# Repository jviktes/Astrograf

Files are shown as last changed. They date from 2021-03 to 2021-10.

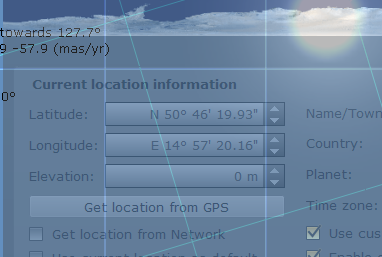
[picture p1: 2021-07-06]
AstroCalc/Images/2021-07-05 17_04_42-Stellarium 0.21.0.png

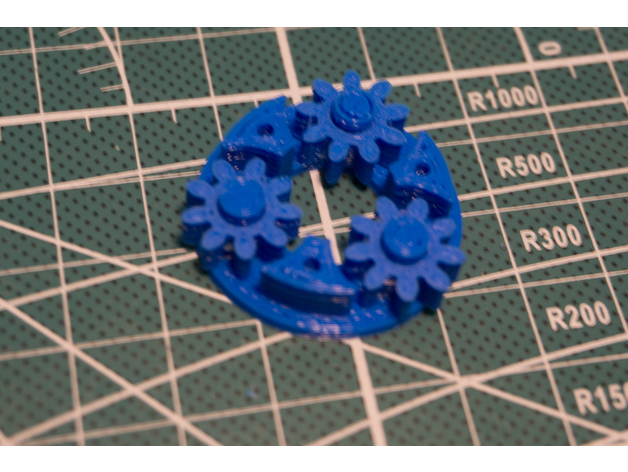
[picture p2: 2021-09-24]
3DPrint/Modular_planetary_gearbox__1024/images/89b79a1b9589dc2109ac6e01d3e06d19_preview_featured.jpg

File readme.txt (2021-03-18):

Projekt má několik částí:
1/ Teorie pro azimutánní montáž vs paraliktická - pro začátek je jednodušší azimutání, dále pak mohu využít pro sledování letadel, AM je výhodná pro zemské sledování
Z Planetiriá si najdu objekt a jeho souřadnice, ty pak pošlu an dalekohled a ten se natočí a začne stremovat/fotit 

2/ Pohony - asi zvolím krokový motorek. 
Problémy: při přetížení ztráta kroku - jak to sledovat s nějakou šablonou, možná by pomohly čidla z optické myši a pokud to nějak neodpovídá, pak kalibrovat. Počítat všechny kroky motoru + - a ukazovat pořád aktuální úhel...

3/ Konstrukce:
šnek a převody a další převody do nějakého poměru ,aby asi 50.000 otáček motoru byla jedna otáčka dalekohledu, zvýší se tím asi i přesnost

4/ Ovládání:
elegatní přes aplikaci v mobilu nebo PC program

5/ Focení letadel - je to vůbec možné, zkusit na jedné ose, čeká se na spojení s USB dongle odposlechem

Odkazy:
Převodovky a ozubená kola:
https://www.mateza.cz/e-shop/prevodovky/ozubena-kola/ozubena-kola-celni

https://www.astro.cz/clanky/ostatni/teleskopie-dil-ctrnacty-jednoduche-zarizeni-pro-astrografii.html

https://www.ngc7000.com/telescope-motorization.htm

https://www.instructables.com/Star-Track-Arduino-Powered-Star-Pointer-and-Tracke/

Astro tracker

Hotový hodinová strojek:
https://nl.aliexpress.com/item/4000115759057.html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,scm-url:1007.13339.169870.0,pvid:6c359c70-a61f-4515-a4be-b17c4211bed0,tpp_buckets:668%230%23131923%230_668%230%23131923%230_668%23888%233325%2320_668%23888%233325%2320_668%232846%238108%231977_668%232717%237560%23237_668%231000022185%231000066059%230_668%233468%2315617%23817_668%232846%238108%231977_668%232717%237560%23237_668%233164%239976%23517_668%233468%2315617%23817

Cíl:
https://www.moveshootmove.com

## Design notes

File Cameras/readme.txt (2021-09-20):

Kamery přímo do dalekohledu:

https://www.aliexpress.com/item/10000111526603.html

Co mám doma:
computar tv zoom lens t6y5710Amsp - zaostřování, clona atd. pomocí motorků, nástavba k EYE03

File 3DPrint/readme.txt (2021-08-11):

Worm gearbox 1:60
https://www.thingiverse.com/thing:3079719

Compound Planetary Gearbox For Robotic Arm Project 43.3:1 
https://www.thingiverse.com/thing:2101218/comments

Hujer - modulární planetová převodovka
https://www.thingiverse.com/thing:2586962

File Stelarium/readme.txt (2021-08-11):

Původní projekt:

https://www.instructables.com/Control-Your-Telescope-Using-Stellarium-Arduino/
!!! pozor tento projekt není zcela funkční !!!

Data zachycená na mySerial = to co se posílá do Stelaria:

AR03:33:55#txDEC+86?08:57
AR03:35:04#txDEC+86?08:57
AR03:36:55#txDEC+86?08:57#

Spouštět jako admin!
Správný protokol.

Alternativy
http://www.skytechx.eu/?page=home

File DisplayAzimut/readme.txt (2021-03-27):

V některých knihovnách je problém, že neukazují přímo úhly, ale nějaké přírústky v čase nebo co.

tato knihovna (AHRS) ukazuje rovnou úhly:
AHRS is an acronym for Attitude and Heading Reference System, a system generally used for aircraft of any sort to determine heading, pitch, roll, altitude etc.

https://learn.adafruit.com/ahrs-for-adafruits-9-dof-10-dof-breakout?v

Pro LCD display toto:
https://lastminuteengineers.com/i2c-lcd-arduino-tutorial/

Pokusy s měřením pomocí gyroskoupu:

úhly mají v bytě podivné odchylky

magnetická odchylka pro dané místo
https://www.ngdc.noaa.gov/geomag/calculators/magcalc.shtml?#declination

Zde se počítá azimut - mezi 2 body
https://www.calcmaps.com/map-coordinates/ -> https://www.omnicalculator.com/other/azimuth
Naměřené úhly:
50.76197,15.09745 domov
50.73269,14.98462 Jested

LBC --> komín Rýnovice: 125.88 vzdálenost: 4.4km
LBC -->Ještěd: 247.74, vzdálenost: 8.58km

Odchylka na Ješted je asi 10st, na komín asi 20, stejně tak na Měsíc. Snaha o kalibraci aplikace Kompas v mobilu, ale také ukazuje podivnosti, na Ještě d celkem ok +-2 st, možná i přesněji, na komín ale stále +-10, nerozumím. Je nutná důsledná kalibrace sensoru např. podle https://learn.adafruit.com/adafruit-sensorlab-magnetometer-calibration?view=all
--> opouštím od magnetických sensorů, jsou velice nepřesné a pokusím se udělat to přes motorky a počítání kroků a kalibraci se zaměřením na Ještěd a odpočtu známého azimutu.

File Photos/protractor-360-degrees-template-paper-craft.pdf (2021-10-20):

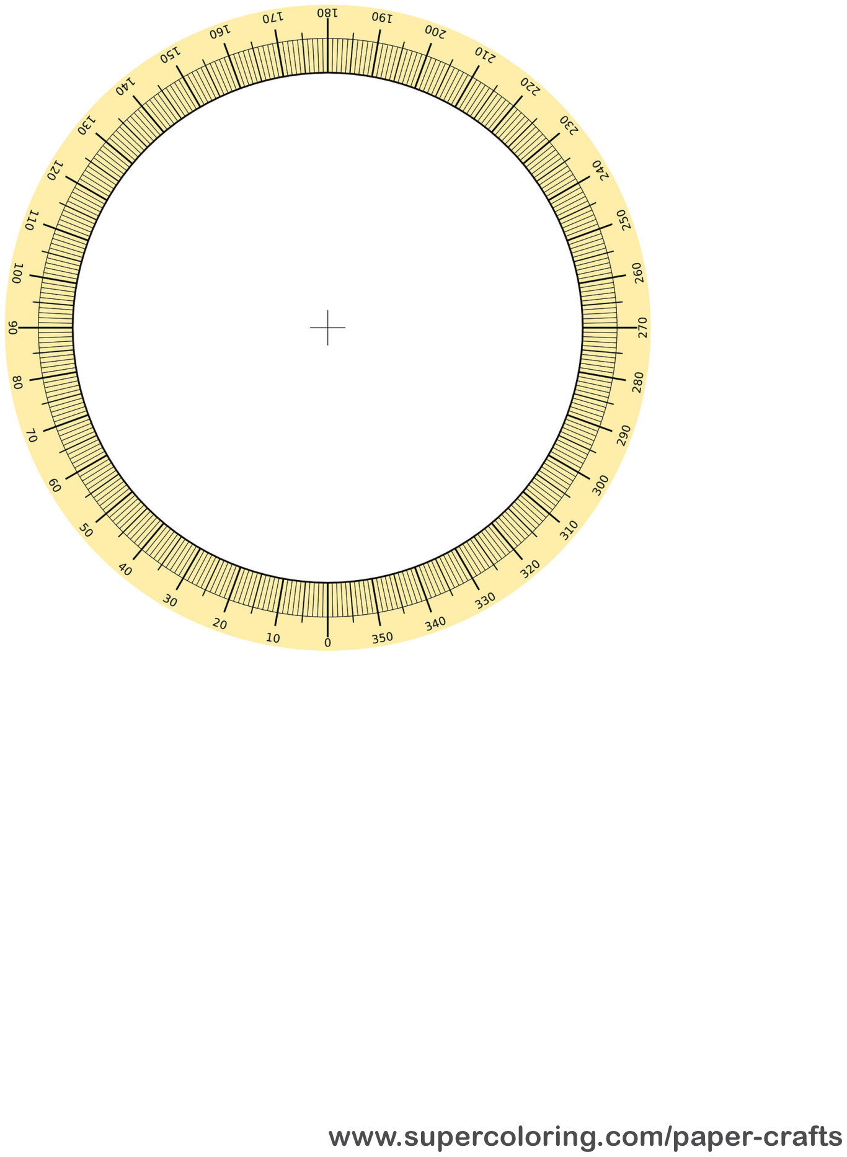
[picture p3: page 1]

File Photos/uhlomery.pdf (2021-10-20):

# Sada úhlomìrù

# Václav Piskaè, Brno 2010

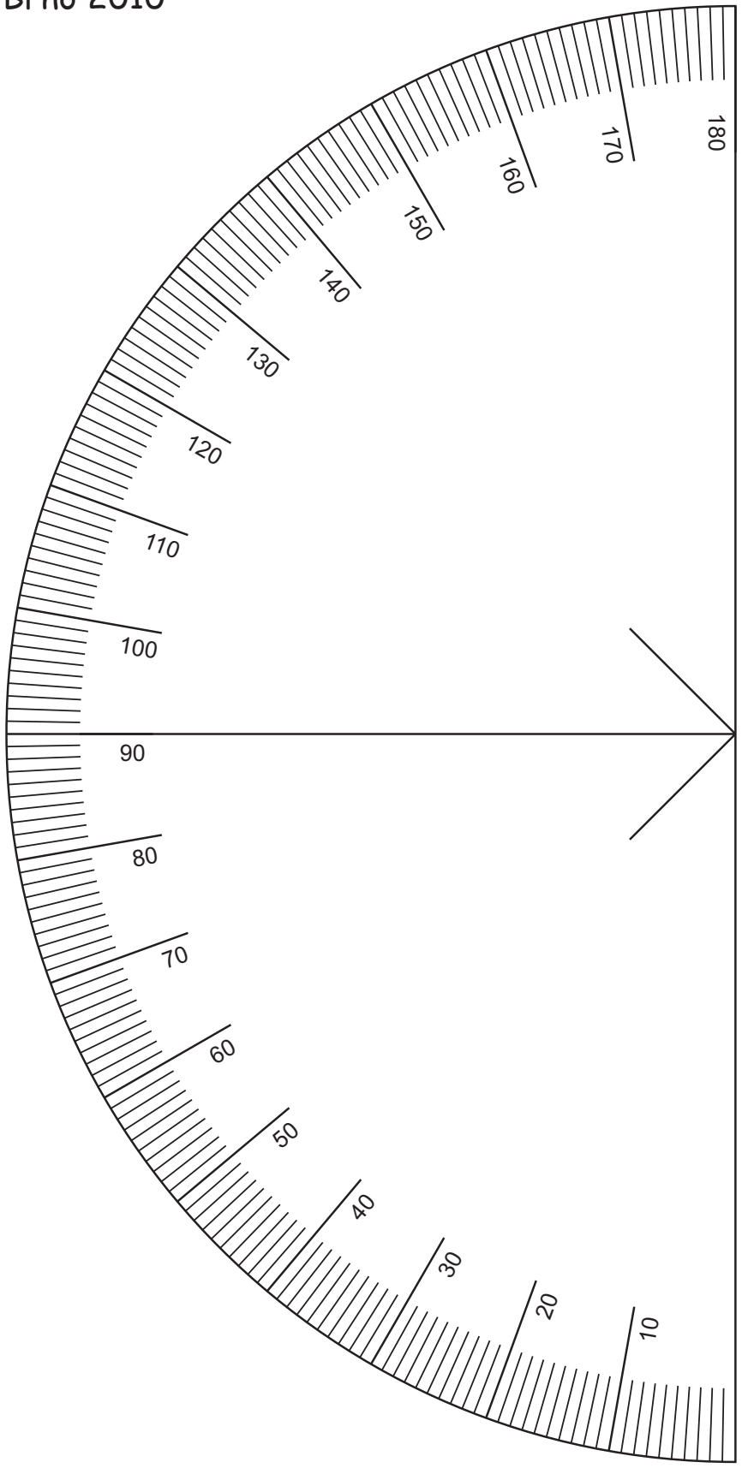
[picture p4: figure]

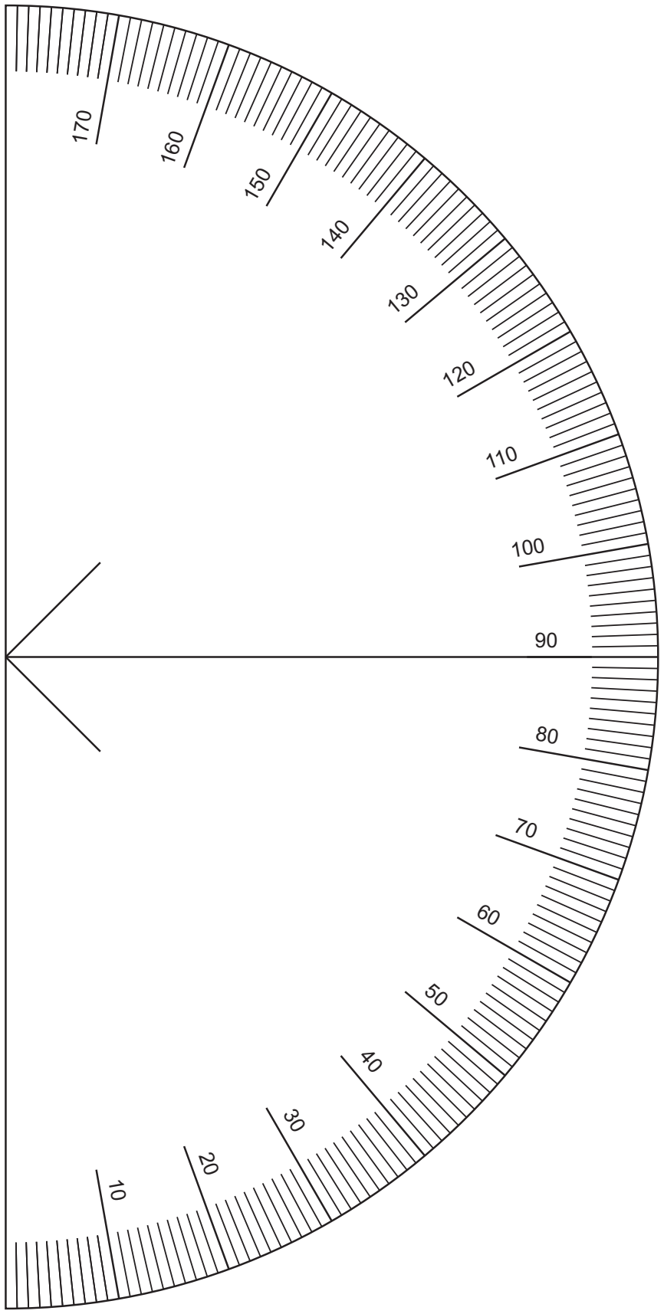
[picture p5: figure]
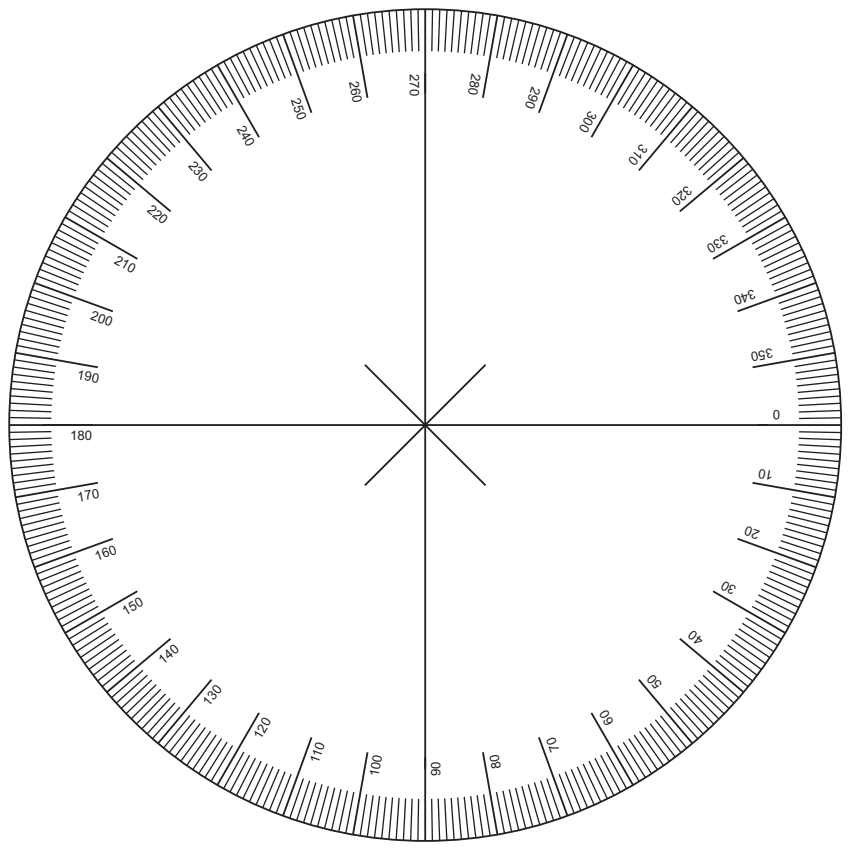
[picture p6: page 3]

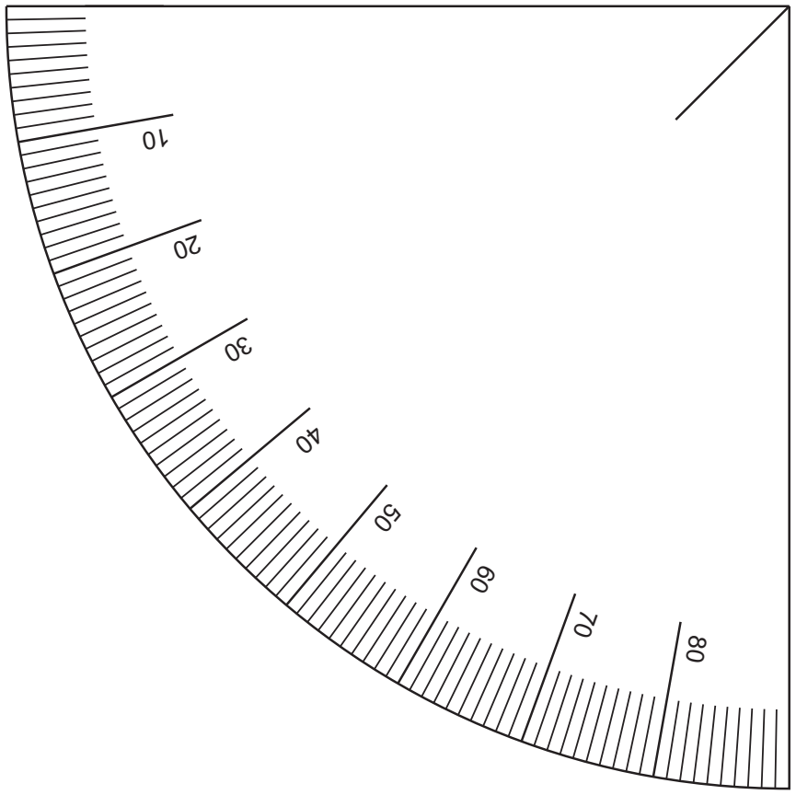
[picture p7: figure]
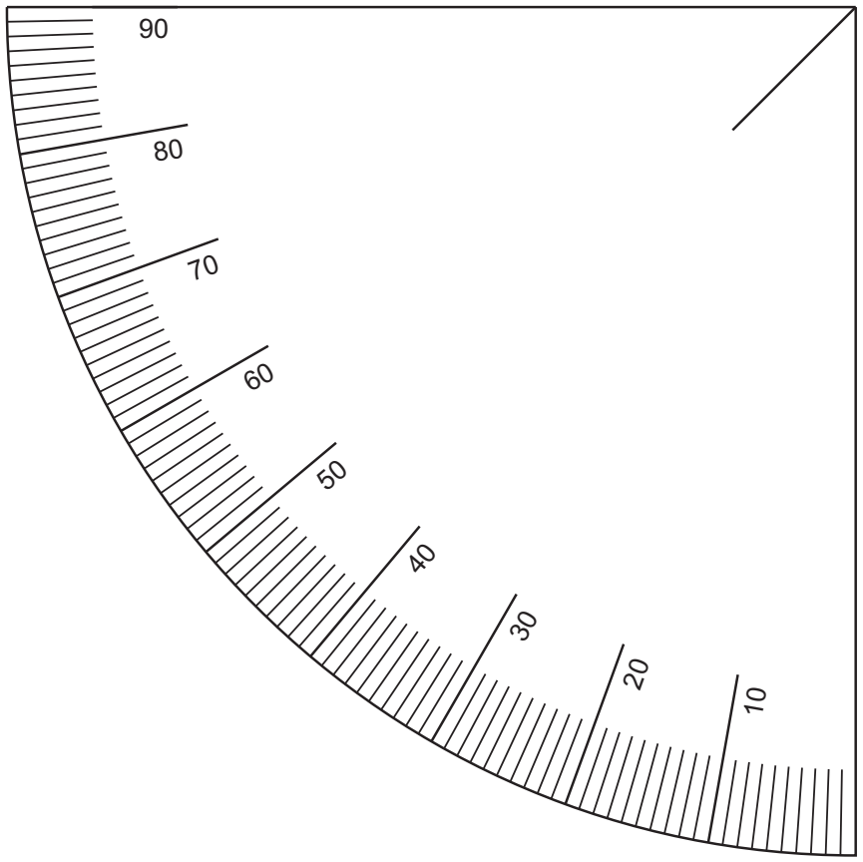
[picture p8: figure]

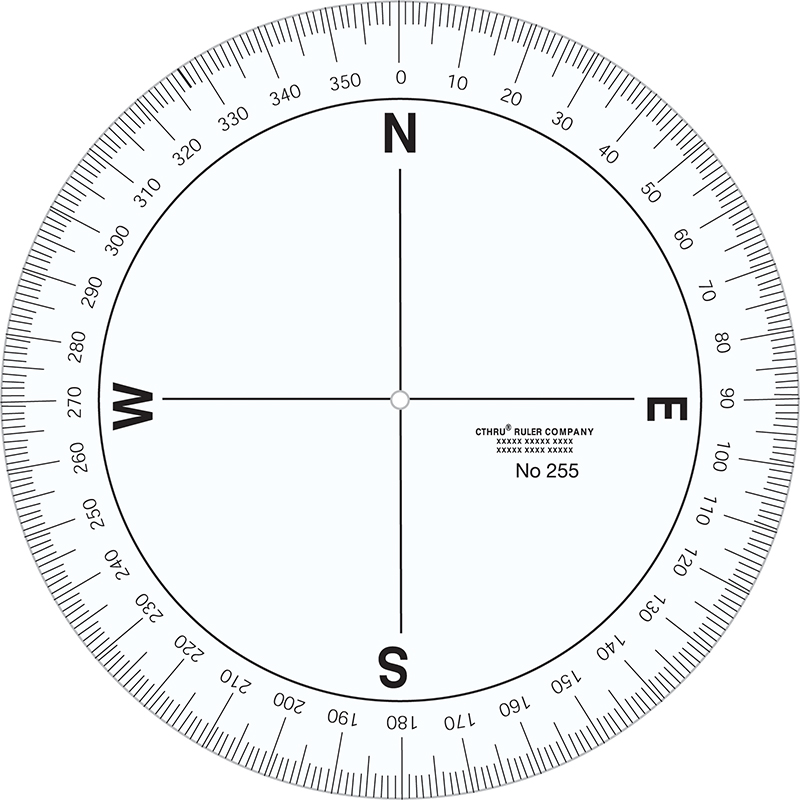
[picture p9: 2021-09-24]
Photos/azimut.jpg

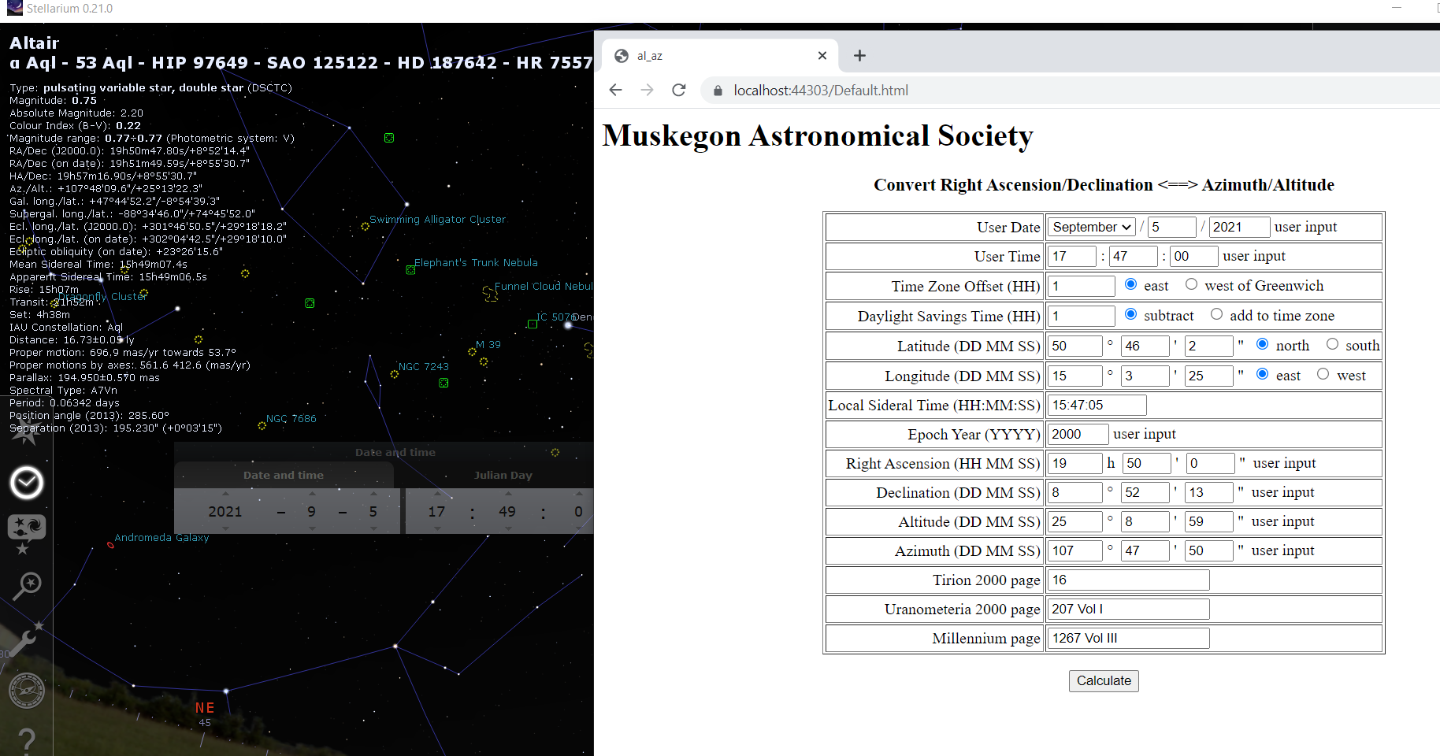
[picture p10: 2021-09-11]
Photos/2021-09-05 17_49_00-al_az.png

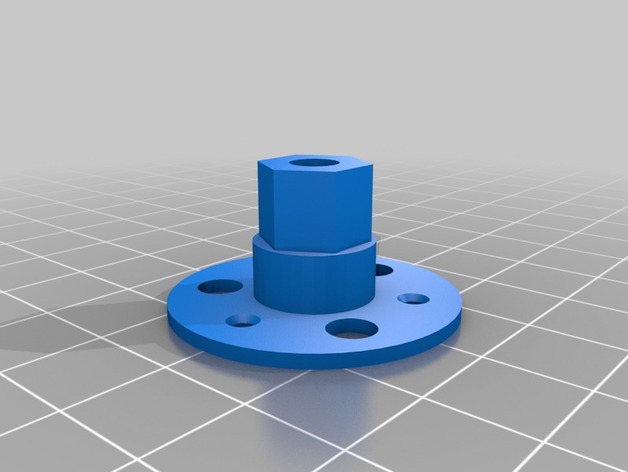
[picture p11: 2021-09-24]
3DPrint/Modular_planetary_gearbox__1024/images/2216a9d065c5c32abdc0daf6dab2dc04_preview_featured.jpg

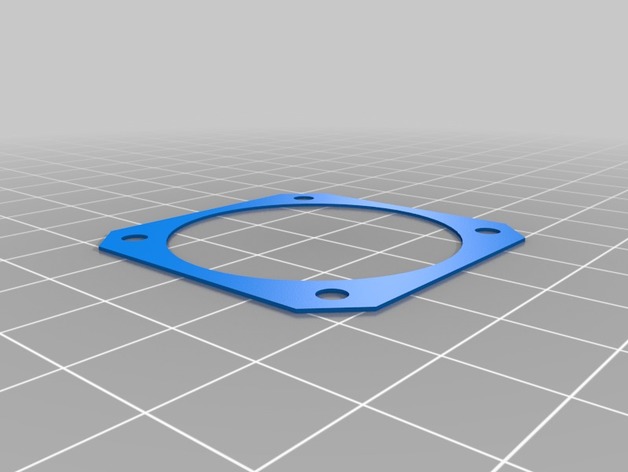
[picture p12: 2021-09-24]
3DPrint/Modular_planetary_gearbox__1024/images/d6676b2a3f6b6646a97d470c4b08ee19_preview_featured.jpg

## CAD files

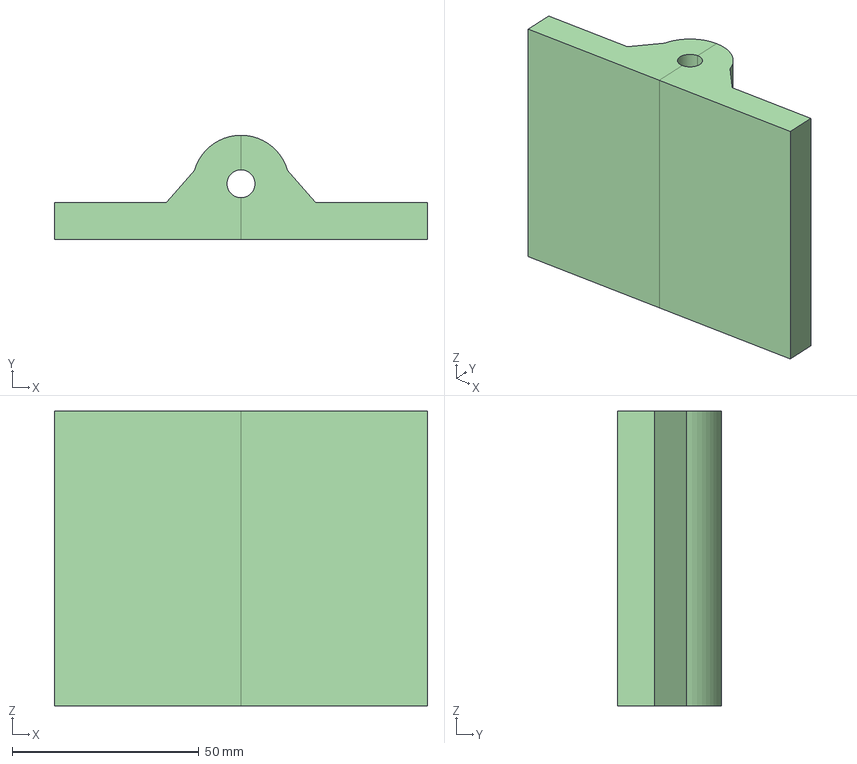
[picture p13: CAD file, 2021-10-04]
3DPrint/Models/Zrcadlovka_1.FCStd
100.0 x 28.0 x 79.0 mm
refer_vzpera
BaseFeature001

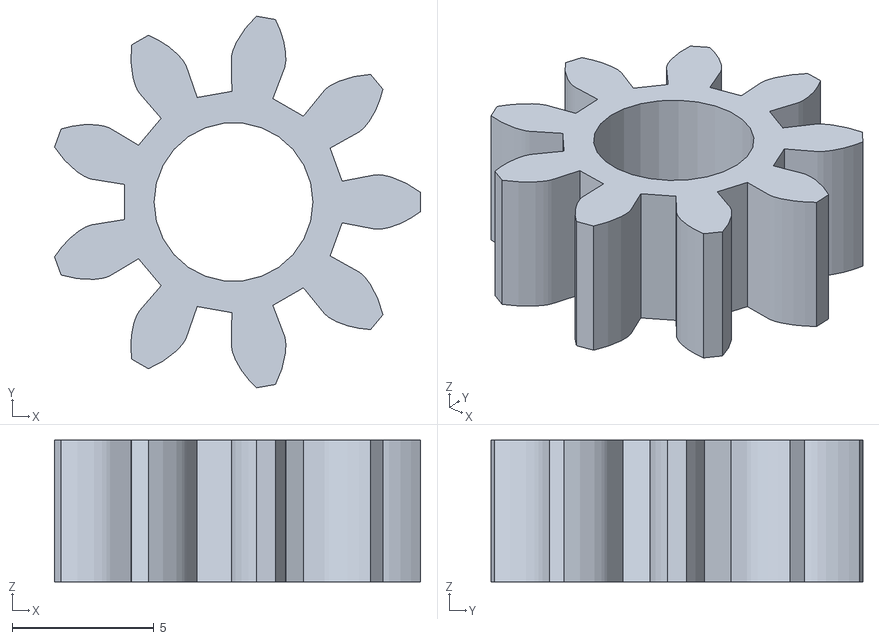
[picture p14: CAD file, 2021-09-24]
3DPrint/Modular_planetary_gearbox__1024/files/planet_gear_v1.stl
12.9 x 13.1 x 5.00

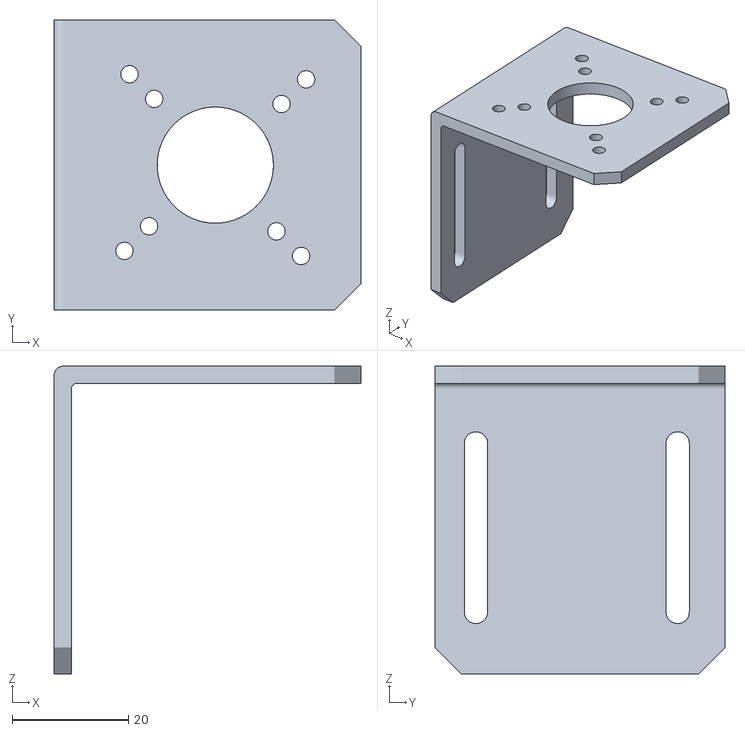
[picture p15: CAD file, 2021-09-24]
3DPrint/Nema_17_holder/files/Mounting_Bracket_for_Geared_Nema_17_-_ST-M1.stl
52.8 x 50.0 x 53.0

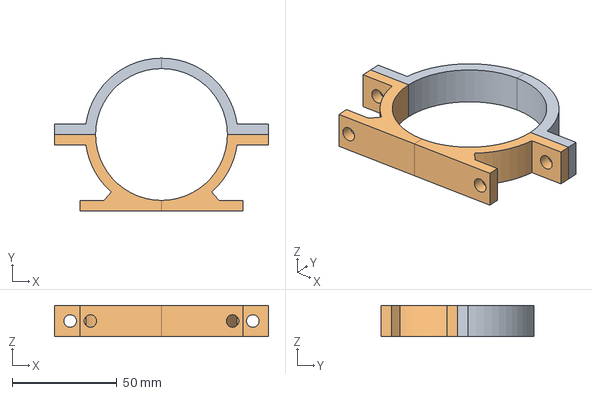
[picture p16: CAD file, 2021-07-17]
3DPrint/Telescope3D/Sverka.FCStd
102.3 x 73.0 x 15.0 mm
HorniDil
SpodniDil

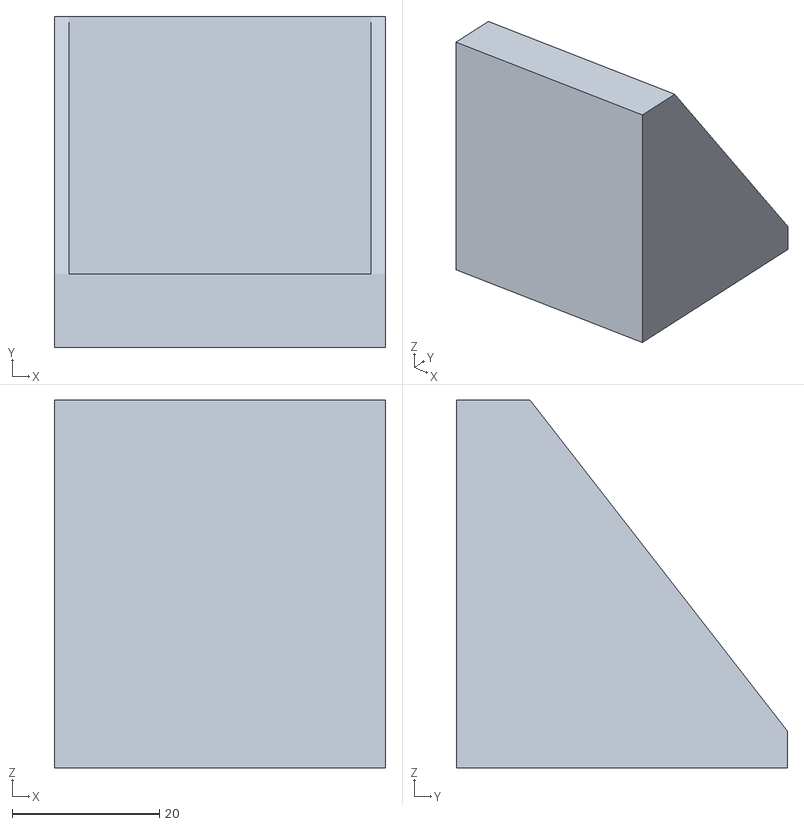
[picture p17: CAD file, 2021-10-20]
DSLR/3D_models/_backUp/Drzak_Y28_motoru_2.stl
45.0 x 45.0 x 50.0

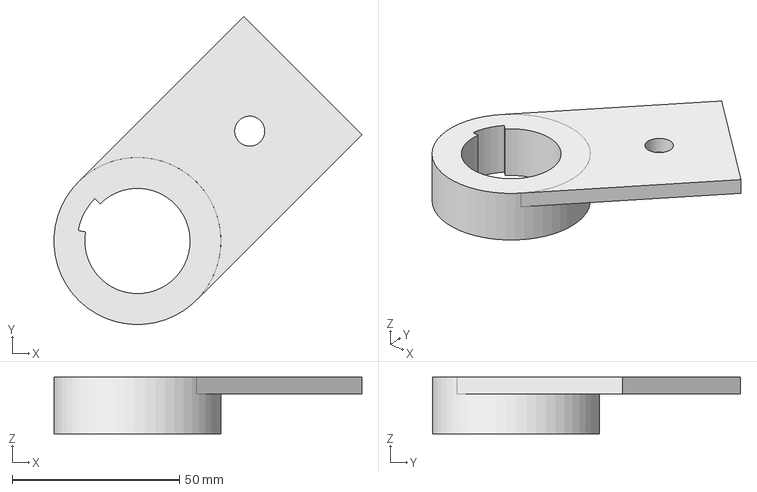
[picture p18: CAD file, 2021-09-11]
3DPrint/Models/azimut_mount.FCStd
92.1 x 92.2 x 17.0 mm

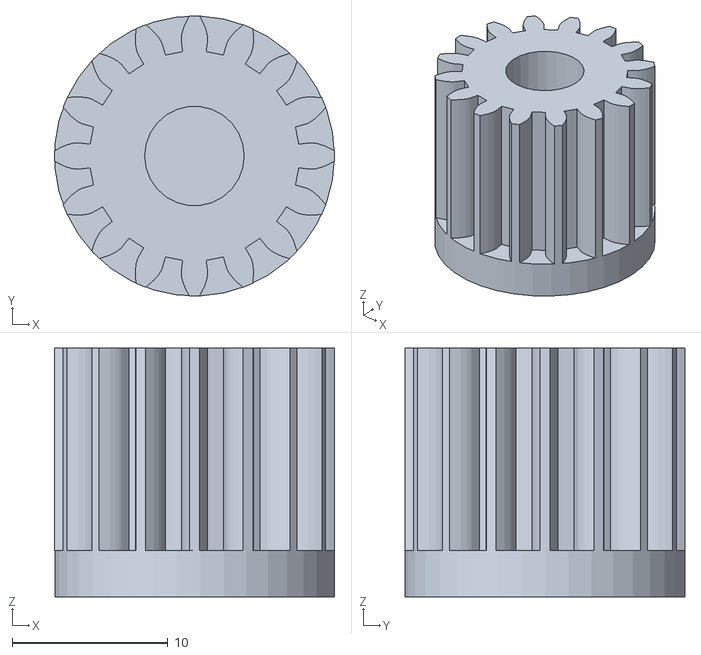
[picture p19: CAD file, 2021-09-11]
3DPrint/Models/tisk/ozub_kolo_poten_16.stl
18.0 x 18.0 x 16.0

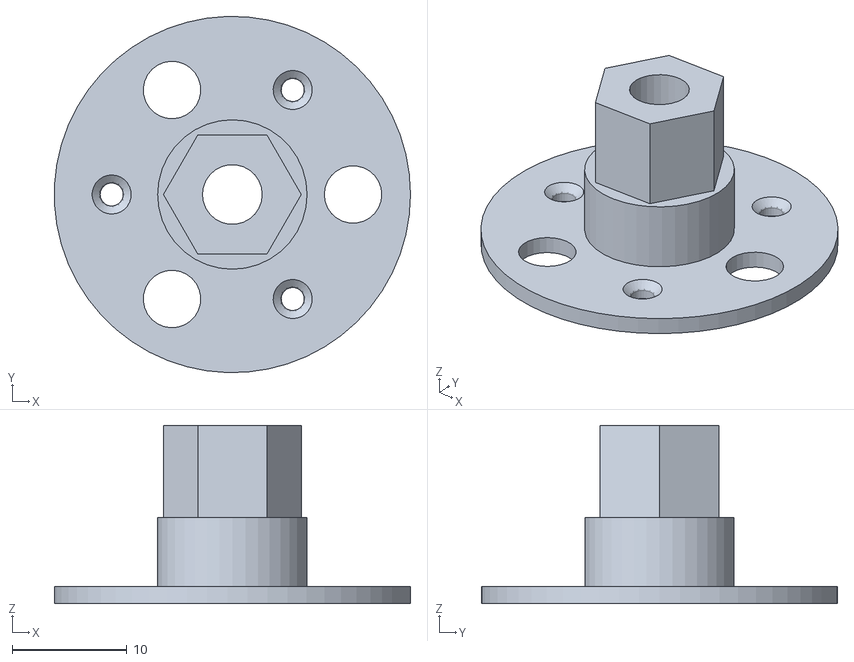
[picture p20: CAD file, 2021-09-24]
3DPrint/Modular_planetary_gearbox__1024/files/top_gear_v1.stl
31.0 x 31.0 x 15.5

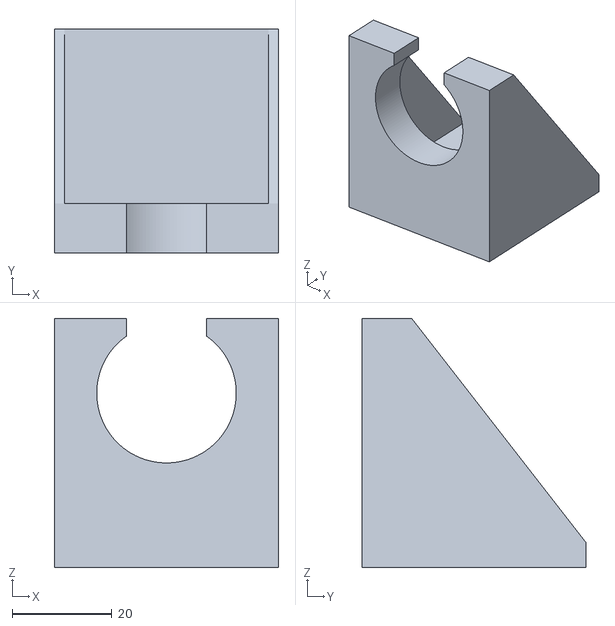
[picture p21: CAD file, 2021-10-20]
DSLR/3D_models/_backUp/Drzak_Y28_motoru_3-Fusion.stl
45.0 x 45.0 x 50.0

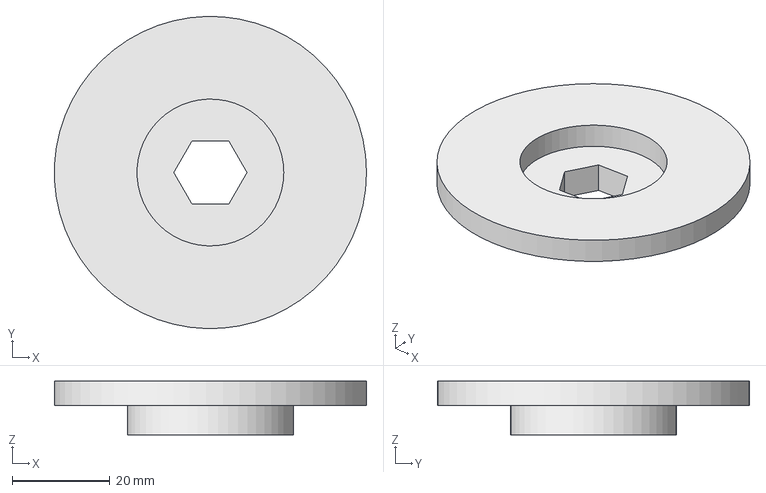
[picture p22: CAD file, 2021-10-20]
DSLR/3D_models/Zrcadlovka_Ozubena_kola_2_zavitova_hridel_priruba.FCStd
64.0 x 64.0 x 11.0 mm

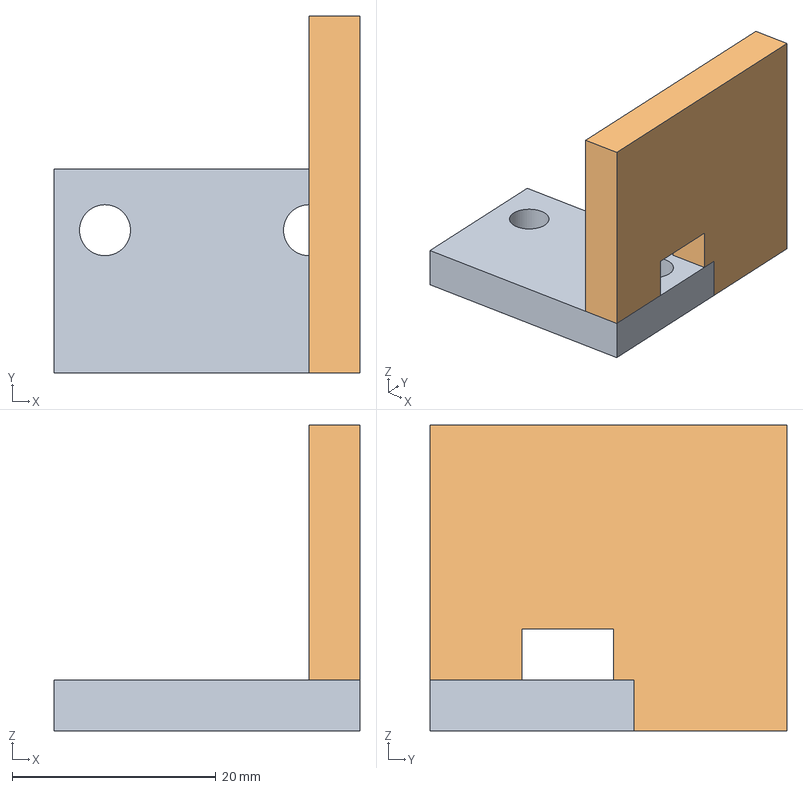
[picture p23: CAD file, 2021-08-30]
3DPrint/Models/drzak_deklinacni_potenciometr.FCStd
30.0 x 35.0 x 30.0 mm

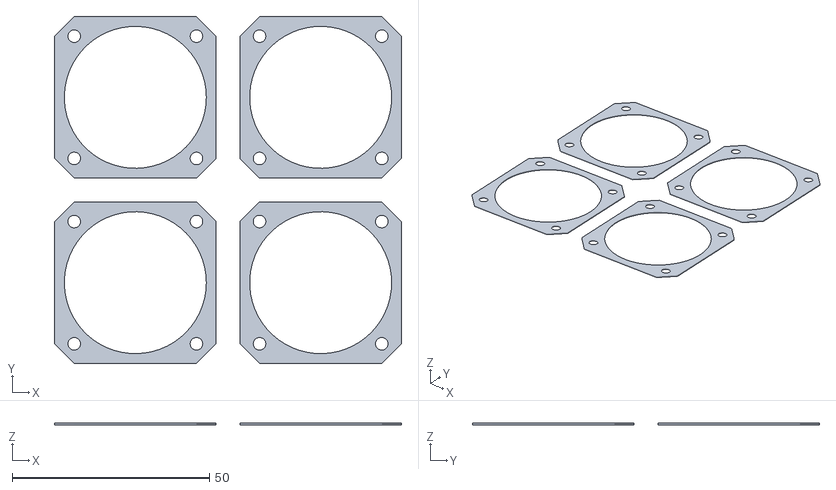
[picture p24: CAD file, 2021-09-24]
3DPrint/Modular_planetary_gearbox__1024/files/print_part_III_v1.stl
88.0 x 88.0 x 0.45

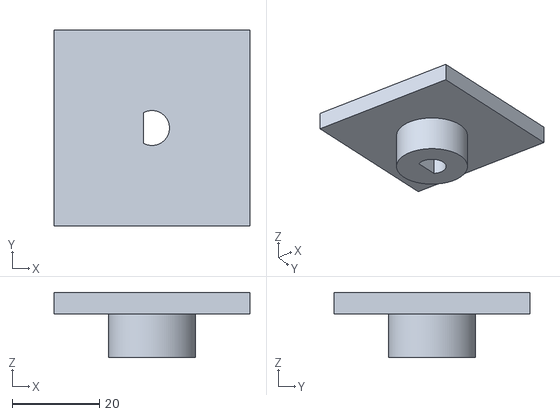
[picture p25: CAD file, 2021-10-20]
DSLR/3D_models/_backUp/hlinik_profil_v_2.stl
45.0 x 45.0 x 15.0

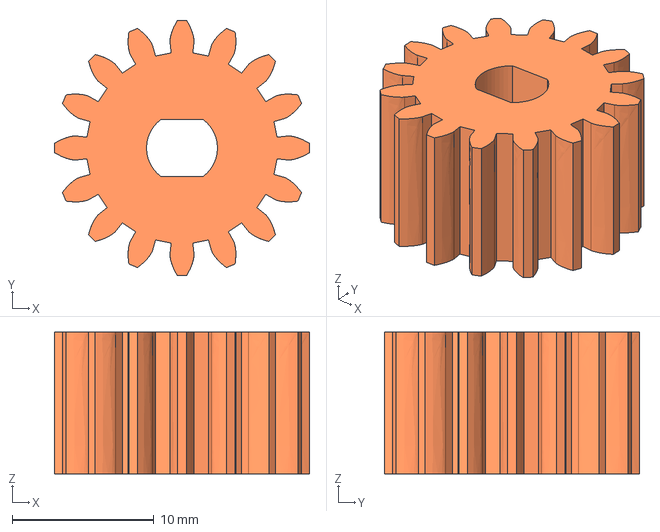
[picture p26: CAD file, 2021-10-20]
DSLR/3D_models/Zrcadlovka_Ozubena_kola_2_uprava_pro_28BYJ.FCStd
18.0 x 18.0 x 10.0 mm

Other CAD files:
DSLR/3D_models/Drzak_Y28_motoru_2.FCStd
3DPrint/Models/tisk/azimut_mount_v5.stl
3DPrint/Models/drzak_deklinacni_potenciometr-Body.stl
3DPrint/Modular_planetary_gearbox__1024/files/carrier_I_v1.stl
3DPrint/Models/azimut_mount_v1.FCStd
3DPrint/Models/azimut_mount_v2.FCStd
3DPrint/Models/new_vzpera1.FCStd
3DPrint/Models/tisk/azimut_mount-AzimutDil.stl
3DPrint/Models/tisk/azimut_mount-Male_ozub_kolo.stl
3DPrint/Models/tisk/azimut_mount-Potenciometer_kolecko.stl
3DPrint/Models/tisk/azimut_mount-Potenciometer_kolecko_v2.stl
3DPrint/Models/tisk/azimut_mount_v3.stl
3DPrint/Models/tisk/azimut_mount_v4.stl
3DPrint/Models/tisk/drzak.stl
3DPrint/Models/tisk/new_vzpera2.stl
3DPrint/Models/tisk/objimka.stl
3DPrint/Models/tisk/objimka_2.stl
3DPrint/Models/tisk/ozub_kolo_potenciometre.stl
3DPrint/Models/tisk/polovicni_ozubi.stl
3DPrint/Modular_planetary_gearbox__1024/files/body_II_v1.stl
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

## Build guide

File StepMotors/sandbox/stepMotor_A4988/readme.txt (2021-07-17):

toto je prvni výkop a hrání si s motorkem

Kontroler - návody:

https://navody.dratek.cz/navody-k-produktum/arduino-cnc-shield-driver-a4988-motor-28byj-48.html
https://dratek.cz/arduino/1133-motor-driver-a4988-pro-reprap-3d-tiskarny.html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

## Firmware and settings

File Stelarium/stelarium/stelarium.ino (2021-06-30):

#include <SoftwareSerial.h>

//**********************************************
// Config your sensor pins and location here!
//**********************************************

// Define the number of pulses that your encoder (1 and 2) gives by turn, and multiply by 4
// In my case: 600 x 15 x 4  (600 pulses by turn; 15 is the gear ratio), so:
long TOTAL_PULSES_PER_ROUND_ENC_1 = 36000;              
long TOTAL_PULSES_PER_ROUND_ENC_2 = 36000;             

// Define DUE's pins
#define ENC_1A 2   // define DUE pin to encoder 1-channel A                     
#define ENC_1B 3   // define DUE pin to encoder 1-channel B  
#define ENC_2A 4   // define DUE pin to encoder 2-channel A  
#define ENC_2B 5   // define DUE pin to encoder 2-channel B  

// enter your latitude (example: North 40Âº33'20'') 
//Longitude will be calculated through AR and H.
int POSITION_LATITUDE_HH = 50;    // this means 40Âº North
int POSITION_LATITUDE_MM = 46;
int POSITION_LATITUDE_SS = 2;

// enter Pole Star right ascention (AR: HH:MM:SS)
int POLARKA_AR_HH = 2;    // this means 2 hours, 52 minutes and 16 seconds
int POLARKA_AR_MM = 58;
int POLARKA_AR_SS = 31;

// enter Pole Star hour angle (H: HH:MM:SS)
int POLARKA_HOUR_CLOCK_HH = 0;//8;
int POLARKA_HOUR_CLOCK_MM = 0;//33;
int POLARKA_HOUR_CLOCK_SS = 0;//24;

SoftwareSerial mySerial(7, 8); // RX, TX - toto slouzi je pro vypis, co posilam na stelarium

unsigned long SEG_SIDERAL = 1003;
const double      CONST_PI = 3.14159265358979324;

volatile int lastEncoded1 = 0;
volatile long encoderValue1 = 0;

volatile int lastEncoded2 = 0;
volatile long encoderValue2 = 0;

char _input_from_Stelarium[20];
//vystupem jsou _AR_Formated_Stelarium a _DEC_Formated_Stelarium = naformatovane hodnoty souradnic v EQ
char _AR_Formated_Stelarium[10];
char _DEC_Formated_Stelarium[11];

long TSL;
unsigned long t_ciclo_acumulado = 0, time_running_arduino;

long Az_tel_s, Alt_tel_s;

long AR_tel_s, DEC_tel_s;

double cos_phi, sin_phi;

//--------------------------------------------------------------------------------------------------------------------------------------------------------
void setup()
{
  Serial.begin(9600);
  
  pinMode(ENC_1A, INPUT_PULLUP);
  pinMode(ENC_1B, INPUT_PULLUP);
  pinMode(ENC_2A, INPUT_PULLUP);
  pinMode(ENC_2B, INPUT_PULLUP);

  attachInterrupt(digitalPinToInterrupt(ENC_1A), Encoder_Interrupt_1, CHANGE);
  attachInterrupt(digitalPinToInterrupt(ENC_1B), Encoder_Interrupt_1, CHANGE);
  attachInterrupt(digitalPinToInterrupt(ENC_2A), Encoder_Interrupt_2, CHANGE);
  attachInterrupt(digitalPinToInterrupt(ENC_2B), Encoder_Interrupt_2, CHANGE);

  cos_phi = cos((((POSITION_LATITUDE_HH * 3600) + (POSITION_LATITUDE_MM * 60) + POSITION_LATITUDE_SS) / 3600.0) * CONST_PI / 180.0);
  sin_phi = sin((((POSITION_LATITUDE_HH * 3600) + (POSITION_LATITUDE_MM * 60) + POSITION_LATITUDE_SS) / 3600.0) * CONST_PI / 180.0);

  TSL = POLARKA_AR_HH * 3600 + POLARKA_AR_MM * 60 + POLARKA_AR_SS + POLARKA_HOUR_CLOCK_HH * 3600 + POLARKA_HOUR_CLOCK_MM * 60 + POLARKA_HOUR_CLOCK_SS;
  while (TSL >= 86400) TSL = TSL - 86400;


  mySerial.begin(9600);
  
  Serial.println("setup ok");
  mySerial.write("setup ok");

  
}

//--------------------------------------------------------------------------------------------------------------------------------------------------------
void loop()
{
  time_running_arduino = millis(); //cas od spusteni arduina
  if (t_ciclo_acumulado >= SEG_SIDERAL) {
    TSL++; // toto je podivne
    t_ciclo_acumulado = t_ciclo_acumulado - SEG_SIDERAL;
    if (TSL >= 86400) {
      TSL = TSL - 86400;
    }
  }

  read_sensors();
  AZ_to_EQ();

  if (Serial.available() > 0) 
  {communication();}

  time_running_arduino = millis() - time_running_arduino;
  t_ciclo_acumulado = t_ciclo_acumulado + time_running_arduino;
  
}

//--------------------------------------------------------------------------------------------------------------------------------------------------------
void communication()
{
  mySerial.write("communication:");

  int i = 0;

  _input_from_Stelarium[i++] = Serial.read();
  delay(5);


  //While connected to Arduino, periodically Stellarium sends 2 strings: ":GR#" - ready to receive RA and ":GD#" - to receive DEC.

  while ((_input_from_Stelarium[i++] = Serial.read()) != '#') {
    delay(5);
  }
  _input_from_Stelarium[i] = '\0';

    mySerial.write("_AR_Formated_Stelarium");
    mySerial.write(_AR_Formated_Stelarium);
    mySerial.write("_DEC_Formated_Stelarium");
    mySerial.write(_DEC_Formated_Stelarium);
    
  if (_input_from_Stelarium[1] == ':' && _input_from_Stelarium[2] == 'G' && _input_from_Stelarium[3] == 'R' && _input_from_Stelarium[4] == '#') {
    Serial.print(_AR_Formated_Stelarium);

  }

  if (_input_from_Stelarium[1] == ':' && _input_from_Stelarium[2] == 'G' && _input_from_Stelarium[3] == 'D' && _input_from_Stelarium[4] == '#') {
    Serial.print(_DEC_Formated_Stelarium);
  }
}

//--------------------------------------------------------------------------------------------------------------------------------------------------------
void read_sensors() {

    //fake:
   // encoderValue2= encoderValue2+200;
    //delay(1000);

  if (encoderValue2 >= TOTAL_PULSES_PER_ROUND_ENC_2 || encoderValue2 <= -TOTAL_PULSES_PER_ROUND_ENC_2) {
    encoderValue2 = 0;
  }
  
  //Alta teleskop:
  int _enc_1 = encoderValue1 / 1500;
  long encoder1_temp = encoderValue1 - (_enc_1 * 1500);
  long map1 = _enc_1 * map(1500, 0, TOTAL_PULSES_PER_ROUND_ENC_1, 0, 1296000); //map(value, fromLow, fromHigh, toLow, toHigh)
  Alt_tel_s = map1 + map(encoder1_temp, 0, TOTAL_PULSES_PER_ROUND_ENC_1, 0, 1296000);

  //Azimut teleskop:
  int _enc_2 = encoderValue2 / 1500;
  long encoder2_temp = encoderValue2 - (_enc_2 * 1500);

  long map2 = _enc_2 * map(1500, 0, TOTAL_PULSES_PER_ROUND_ENC_2, 0, 1296000);
  Az_tel_s  = map2 + map (encoder2_temp, 0, TOTAL_PULSES_PER_ROUND_ENC_2, 0, 1296000);

  if (Az_tel_s < 0) Az_tel_s = 1296000 + Az_tel_s;
  if (Az_tel_s >= 1296000) Az_tel_s = Az_tel_s - 1296000 ;

  mySerial.write("Az_tel_s:"+Az_tel_s);
  mySerial.write("Alt_tel_s:"+ Alt_tel_s);

}

//Metoda volaná pri zmene v pulzu, preruseni:
void Encoder_Interrupt_1() {
  int encoded1 = (digitalRead(ENC_1A) << 1) | digitalRead(ENC_1B);
  int sum  = (lastEncoded1 << 2) | encoded1;
  if (sum == 0b1101 || sum == 0b0100 || sum == 0b0010 || sum == 0b1011) encoderValue1 ++;
  if (sum == 0b1110 || sum == 0b0111 || sum == 0b0001 || sum == 0b1000) encoderValue1 --;
  lastEncoded1 = encoded1;
}

//Metoda volaná pri zmene v pulzu, preruseni:
void Encoder_Interrupt_2() {
  int encoded2 = (digitalRead(ENC_2A) << 1) | digitalRead(ENC_2B);
  int sum  = (lastEncoded2 << 2) | encoded2;

  if (sum == 0b1101 || sum == 0b0100 || sum == 0b0010 || sum == 0b1011) encoderValue2 ++;
  if (sum == 0b1110 || sum == 0b0111 || sum == 0b0001 || sum == 0b1000) encoderValue2 --;
  lastEncoded2 = encoded2;
}

//--------------------------------------------------------------------------------------------------------------------------------------------------------
//vystupem jsou _AR_Formated_Stelarium a _DEC_Formated_Stelarium = naformatovane hodnoty souradnic v EQ
void AZ_to_EQ()
{
  double delta_tel, sin_h, cos_h, sin_A, cos_A, sin_DEC, cos_DEC;
  double H_telRAD, h_telRAD, A_telRAD;
  long H_tel;
  long arHH, arMM, arSS;
  long decDEG, decMM, decSS;
  char sDEC_tel;

  A_telRAD = (Az_tel_s / 3600.0) * CONST_PI / 180.0;
  h_telRAD = (Alt_tel_s / 3600.0) * CONST_PI / 180.0;
  sin_h = sin(h_telRAD);
  cos_h = cos(h_telRAD);
  sin_A = sin(A_telRAD);
  cos_A = cos(A_telRAD);
  delta_tel = asin((sin_phi * sin_h) + (cos_phi * cos_h * cos_A));
  sin_DEC = sin(delta_tel);
  cos_DEC = cos(delta_tel);
  DEC_tel_s = long((delta_tel * 180.0 / CONST_PI) * 3600.0);

  while (DEC_tel_s >= 1296000) {
    DEC_tel_s = DEC_tel_s - 1296000;
  }
  while (DEC_tel_s <= -1296000) {
    DEC_tel_s = DEC_tel_s + 1296000;
  }

  H_telRAD = acos((sin_h - (sin_phi * sin_DEC)) / (cos_phi * cos_DEC));
  H_tel = long((H_telRAD * 180.0 / CONST_PI) * 240.0);

  if (sin_A >= 0) {
    H_tel = 86400 - H_tel;
  }
  AR_tel_s = TSL - H_tel;

  while (AR_tel_s >= 86400) {
    AR_tel_s = AR_tel_s - 86400;
  }
  while (AR_tel_s < 0) {
    AR_tel_s = AR_tel_s + 86400;
  }

  arHH = AR_tel_s / 3600;
  arMM = (AR_tel_s - arHH * 3600) / 60;
  arSS = (AR_tel_s - arHH * 3600) - arMM * 60;
  decDEG = abs(DEC_tel_s) / 3600;
  decMM = (abs(DEC_tel_s) - decDEG * 3600) / 60;
  decSS = (abs(DEC_tel_s) - decDEG * 3600) - decMM * 60;
  (DEC_tel_s < 0) ? sDEC_tel = 45 : sDEC_tel = 43;

  //vystupem jsou _AR_Formated_Stelarium a _DEC_Formated_Stelarium = naformatovane hodnoty souradnic v EQ
  sprintf(_AR_Formated_Stelarium, "%02d:%02d:%02d#", int(arHH), int(arMM), int(arSS));
  sprintf(_DEC_Formated_Stelarium, "%c%02d%c%02d:%02d#", sDEC_tel, int(decDEG), 223, int(decMM), int(decSS));
  
}

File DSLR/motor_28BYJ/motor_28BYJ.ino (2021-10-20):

//Written By Nikodem Bartnik - nikodembartnik.pl
//https://github.com/NikodemBartnik/ArduinoTutorials/tree/master/28BYJ-48

#define STEPPER_PIN_1 9
#define STEPPER_PIN_2 10
#define STEPPER_PIN_3 11
#define STEPPER_PIN_4 12

int inner_step_number = 0;
int stepCount = 0;
double anglePerStep = 5.625;
int gearRatio = 32; //převod přímo v motoru

int totalNumberStepsForOneRevolution = 2048; 
// 360:5,625 = 64 (=počet kroků na 360stupnu bez převodu, 64*32(převod) = 2048 kroků na 1 celou otočku

// * převod 76/16
double extTransmittionGera = 1; //=9728
int delayStepMotor;


void setup() {
  Serial.begin(9600);
  Serial.println("Starting...");
pinMode(STEPPER_PIN_1, OUTPUT);
pinMode(STEPPER_PIN_2, OUTPUT);
pinMode(STEPPER_PIN_3, OUTPUT);
pinMode(STEPPER_PIN_4, OUTPUT);
extTransmittionGera = 76.000/16.000; //=9728
delayStepMotor =8881;//25;//8881 ;//(60*1000)/(totalNumberStepsForOneRevolution*extTransmittionGera);
Serial.println("delayStepMotor:");
Serial.println(delayStepMotor);
}

void loop() {

    OneStep(true);
    
    inner_step_number++;
    if(inner_step_number > 3){
    inner_step_number = 0;
    }
    
    //delay(delayStepMotor);
    delay(delayStepMotor);
    Serial.println("loop");
}


void OneStep(bool dir){
    if(dir){
switch(inner_step_number){
  case 0:
  digitalWrite(STEPPER_PIN_1, HIGH);
  digitalWrite(STEPPER_PIN_2, LOW);
  digitalWrite(STEPPER_PIN_3, LOW);
  digitalWrite(STEPPER_PIN_4, LOW);
  break;
  case 1:
  digitalWrite(STEPPER_PIN_1, LOW);
  digitalWrite(STEPPER_PIN_2, HIGH);
  digitalWrite(STEPPER_PIN_3, LOW);
  digitalWrite(STEPPER_PIN_4, LOW);
  break;
  case 2:
  digitalWrite(STEPPER_PIN_1, LOW);
  digitalWrite(STEPPER_PIN_2, LOW);
  digitalWrite(STEPPER_PIN_3, HIGH);
  digitalWrite(STEPPER_PIN_4, LOW);
  break;
  case 3:
  digitalWrite(STEPPER_PIN_1, LOW);
  digitalWrite(STEPPER_PIN_2, LOW);
  digitalWrite(STEPPER_PIN_3, LOW);
  digitalWrite(STEPPER_PIN_4, HIGH);
  break;
} 
  }else{
    switch(inner_step_number){
  case 0:
  digitalWrite(STEPPER_PIN_1, LOW);
  digitalWrite(STEPPER_PIN_2, LOW);
  digitalWrite(STEPPER_PIN_3, LOW);
  digitalWrite(STEPPER_PIN_4, HIGH);
  break;
  case 1:
  digitalWrite(STEPPER_PIN_1, LOW);
  digitalWrite(STEPPER_PIN_2, LOW);
  digitalWrite(STEPPER_PIN_3, HIGH);
  digitalWrite(STEPPER_PIN_4, LOW);
  break;
  case 2:
  digitalWrite(STEPPER_PIN_1, LOW);
  digitalWrite(STEPPER_PIN_2, HIGH);
  digitalWrite(STEPPER_PIN_3, LOW);
  digitalWrite(STEPPER_PIN_4, LOW);
  break;
  case 3:
  digitalWrite(STEPPER_PIN_1, HIGH);
  digitalWrite(STEPPER_PIN_2, LOW);
  digitalWrite(STEPPER_PIN_3, LOW);
  digitalWrite(STEPPER_PIN_4, LOW);
 
  
} 
  }

}

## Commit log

2021-03-27 serial print misto display
2021-08-11 Add files via upload
    vzpera pro šrouby, pro deklinační osu
    [new_vzpera2.FCStd, new_vzpera2.stl]
2021-08-11 Add files via upload
    Objimka pro trubku telescopu
    [Objimka_teleskope.FCStd]
2021-08-23 azimut monzaz
    moje reseni jako nastavba na dalekohled
    [azimut_mount.FCStd, azimut_mount_v1.FCStd]
2021-08-23 tisky pro 3D
    [azimut_mount-Male_ozub_kolo.stl, drzak.stl, new_vzpera2.stl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]
2021-08-27 potenciometr spolupracujici se stelariem
    [azimut_mount.FCStd]
2021-08-27 oprava potenciometr kolecka 3d
    [azimut_mount-Potenciometer_kolecko.stl, azimut_mount-Potenciometer_kolecko_v2.stl, azimut_mount_v2.FCStd]
2021-08-28 ozubi na vzperu pro deklinacni osu
    [Sverka.FCStd, new_vzpera2.FCStd, polovicni_ozubi.stl]
2021-08-28 dodelavky vzpery
    [new_vzpera2.FCStd]
2021-08-30 deklinacni potenciometer
    [drzak_deklinacni_potenciometr-Body.stl, drzak_deklinacni_potenciometr.FCStd, ozub_kolo_potenciometre.stl]
2021-09-06 organizacni zmeny v projektu
    [Sverka.FCStd]
2021-09-08 vylepseni drzaku azimut potenviometru
    [azimut_mount-AzimutDil.stl, azimut_mount.FCStd, azimut_mount_v3.stl]
2021-09-11 upravy modelu - posun diry pro azimu poten
    [azimut_mount.FCStd, azimut_mount_v4.stl, azimut_mount_v5.stl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]
2021-09-11 funkcni nataceni motorku podle zadaneho uhlu
2021-09-14 ovladani motorku z konzolovky Stelarium
2021-09-14 pridani metod pro posilani dat na arduino s motorkama
2021-09-22 upravy kodu
    toto je funkcni kod pro azimut motor
2021-09-24 pridani projektu od Hujera - modularni planetova prevodovka
    [Mounting_Bracket_for_Geared_Nema_17_-_ST-M1.stl, body_II_v1.stl, body_I_v1.stl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]
2021-10-04 uklid stl souboru
    [azimut_mount-AzimutDil.stl, azimut_mount_v3.stl, azimut_mount_v4.stl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]
2021-10-04 3d model ozubenych kol a drazaku ana Zrcadlovka projekt
    [Zrcadlovka_1.FCStd, new_vzpera1.FCStd]
2021-10-05 nastaveni krokoveho motoru
2021-10-05 3d modely pro zrcadlovku
    [MaleKoloCelek.stl, VelkeKoloCelek.stl, Zrcadlovka_Ozubena_kola.FCStd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]
2021-10-06 uprava pro krokovy motor
    otestovano bez prevodu
2021-10-20 uprava pro krokovy motor_28BYJ
2021-10-20 zalohy atd.
    [Drzak_Y28_motoru_2.stl, Drzak_Y28_motoru_3-Fusion.stl, MaleKoloCelek.stl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]
